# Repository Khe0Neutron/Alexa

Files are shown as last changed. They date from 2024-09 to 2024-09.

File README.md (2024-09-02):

# Proyecto de Control de Luces con Alexa

Este proyecto permite controlar hasta ocho luces en una casa utilizando comandos de voz a través de Amazon Alexa. Está basado en un ESP32, que se conecta a la red WiFi para recibir las órdenes desde Alexa. También se pueden controlar las luces manualmente utilizando botones físicos conectados al ESP32.

## Características

- **Control de luces con Alexa**: Puedes encender y apagar las luces utilizando comandos de voz.
- **Control manual**: Cada luz puede ser controlada manualmente mediante botones físicos conectados al ESP32.
- **Retroalimentación de estado**: El ESP32 proporciona retroalimentación del estado de cada luz tanto a través de la consola serial como del estado del relé.
- **Configuración flexible**: Los nombres de los dispositivos (luces) se pueden personalizar en el código.

## Requisitos

- **Hardware:**
  - ESP32
  - 8 relés para controlar las luces
  - 8 botones físicos para control manual
  - LED para indicar estado de conexión WiFi
  - Conexión WiFi

- **Librerías Arduino:**
  - [`WiFi.h`](https://github.com/espressif/arduino-esp32/tree/master/libraries/WiFi)
  - [`Espalexa.h`](https://github.com/Aircoookie/Espalexa)
  - [`AceButton.h`](https://github.com/bxparks/AceButton)

## Configuración del Hardware

- Los pines del ESP32 están conectados a los relés y a los botones físicos. Aquí están las asignaciones de pines utilizadas en el proyecto:
  - **Relés:**
    - Relé 1: GPIO 23
    - Relé 2: GPIO 22
    - Relé 3: GPIO 21
    - Relé 4: GPIO 19
    - Relé 5: GPIO 18
    - Relé 6: GPIO 5
    - Relé 7: GPIO 25
    - Relé 8: GPIO 26
  - **Botones:**
    - Botón 1: GPIO 13
    - Botón 2: GPIO 12
    - Botón 3: GPIO 14
    - Botón 4: GPIO 27
    - Botón 5: GPIO 33
    - Botón 6: GPIO 32
    - Botón 7: GPIO 15
    - Botón 8: GPIO 4
  - **LED de estado WiFi:** GPIO 2

## Instalación y Configuración

1. **Instalación de librerías:**
   - Asegúrate de tener instaladas las librerías mencionadas en la sección de requisitos.

2. **Configuración de WiFi:**
   - Modifica las siguientes líneas en el código para configurar tu red WiFi:
     ```cpp
     const char* ssid = "Red"; // Cambiar nombre de red
     const char* password = "Contraseña"; // Cambiar contraseña de red
     ```

3. **Compilación y carga:**
   - Compila y sube el código al ESP32 utilizando el IDE de Arduino.

4. **Integración con Alexa:**
   - Una vez que el ESP32 esté conectado a la red WiFi, Alexa detectará los dispositivos automáticamente. Puedes controlar las luces diciendo comandos como "Alexa, enciende la luz de la sala".

## Uso

- **Control con Alexa:** Di "Alexa, enciende/apaga [nombre de la luz]" para controlar las luces.
- **Control manual:** Pulsa el botón físico correspondiente para encender o apagar una luz.

## Contribución

Si encuentras algún error o tienes sugerencias para mejorar el proyecto, siéntete libre de abrir un issue o hacer un pull request.

## Funcionamiento
Instalacion de la placa con un modulo Rele de 8 canales

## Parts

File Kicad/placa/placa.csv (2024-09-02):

Source: | /home/neutron/Documentos/Proyectos/Alexa/Kicad/placa/placa.kicad_sch
Date: | vie 01 dic 2023 10:46:34
Tool: | Eeschema 6.0.2+dfsg-1
Generator: | /usr/share/kicad/plugins/bom_csv_grouped_by_value.py
Component Count: | 8
Individual Components:
Item | Qty | Reference(s) | Value | LibPart | Footprint | Datasheet | Check_prices | Description | MANUFACTURER | MF | MP | PARTREV | Package | STANDARD | SnapEDA_Link
 |  | C1 | C | Device:C | Capacitor_THT:CP_Radial_D4.0mm_P2.00mm | ~
 |  | C2 | C | Device:C | Capacitor_THT:CP_Radial_D4.0mm_P2.00mm | ~
 |  | J1 | Conn_01x02 | Connector_Generic:Conn_01x02 | Connector_PinHeader_2.54mm:PinHeader_1x02_P2.54mm_Vertical | ~
 |  | J2 | Conn_01x02 | Connector_Generic:Conn_01x02 | Connector_PinHeader_2.54mm:PinHeader_1x02_P2.54mm_Vertical | ~
 |  | J3 | Conn_01x10 | Connector_Generic:Conn_01x10 | Connector_PinHeader_2.54mm:PinHeader_1x10_P2.54mm_Vertical | ~
 |  | U1 | ESP32-DEVKITC | ESP32-DEVKITC:ESP32-DEVKITC | ESP32-DEVKITC:MODULE_ESP32-DEVKITC |  | https://www.snapeda.com/parts/ESP32-DEVKITC/Espressif+Systems/view-part/?ref=eda | ESP32-WROOM-32UE series Transceiver; 802.11 b/g/n (Wi-Fi, WiFi, WLAN), Bluetooth ® Smart Ready 4.x Dual Mode Evaluation Board | ESPRESSIF | Espressif Systems | ESP32-DEVKITC | N/A | None | Manufacturer Recommendations | https://www.snapeda.com/parts/ESP32-DEVKITC/Espressif+Systems/view-part/?ref=snap
 |  | U2 | LM1117-3.3 | Regulator_Linear:LM1117-3.3 | lm1117:TO254P1054X470X1955-3 | http://www.ti.com/lit/ds/symlink/lm1117.pdf
 |  | U3 | TXS0108EPW | Logic_LevelTranslator:TXS0108EPW | ESP32-DEVKITC:txs0108 | www.ti.com/lit/ds/symlink/txs0108e.pdf
Collated Components:
Item | Qty | Reference(s) | Value | LibPart | Footprint | Datasheet | Check_prices | Description | MANUFACTURER | MF | MP | PARTREV | Package | STANDARD | SnapEDA_Link
1 | 2 | C1, C2 | C | Device:C | Capacitor_THT:CP_Radial_D4.0mm_P2.00mm | ~
2 | 2 | J1, J2 | Conn_01x02 | Connector_Generic:Conn_01x02 | Connector_PinHeader_2.54mm:PinHeader_1x02_P2.54mm_Vertical | ~
3 | 1 | J3 | Conn_01x10 | Connector_Generic:Conn_01x10 | Connector_PinHeader_2.54mm:PinHeader_1x10_P2.54mm_Vertical | ~
4 | 1 | U1 | ESP32-DEVKITC | ESP32-DEVKITC:ESP32-DEVKITC | ESP32-DEVKITC:MODULE_ESP32-DEVKITC |  | https://www.snapeda.com/parts/ESP32-DEVKITC/Espressif+Systems/view-part/?ref=eda | ESP32-WROOM-32UE series Transceiver; 802.11 b/g/n (Wi-Fi, WiFi, WLAN), Bluetooth ® Smart Ready 4.x Dual Mode Evaluation Board | ESPRESSIF | Espressif Systems | ESP32-DEVKITC | N/A | None | Manufacturer Recommendations | https://www.snapeda.com/parts/ESP32-DEVKITC/Espressif+Systems/view-part/?ref=snap
5 | 1 | U2 | LM1117-3.3 | Regulator_Linear:LM1117-3.3 | lm1117:TO254P1054X470X1955-3 | http://www.ti.com/lit/ds/symlink/lm1117.pdf
6 | 1 | U3 | TXS0108EPW | Logic_LevelTranslator:TXS0108EPW | ESP32-DEVKITC:txs0108 | www.ti.com/lit/ds/symlink/txs0108e.pdf

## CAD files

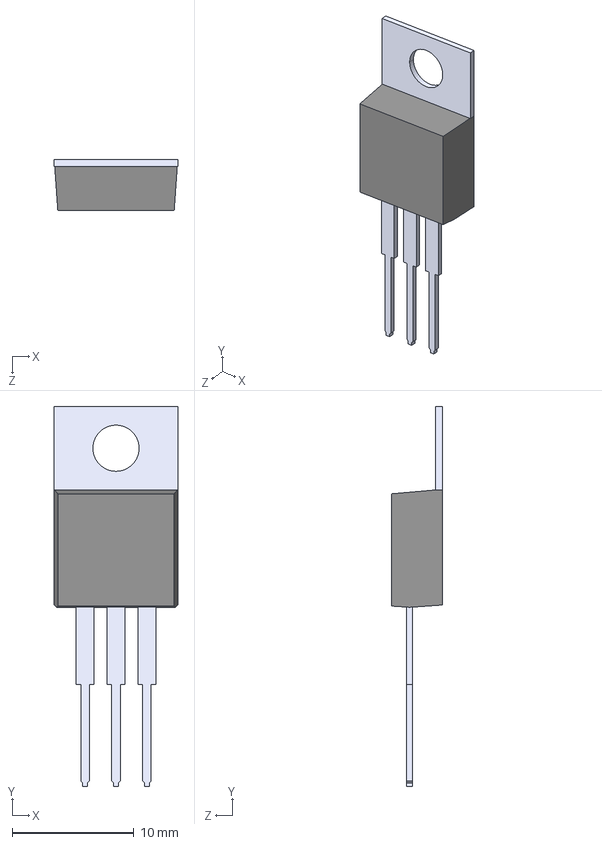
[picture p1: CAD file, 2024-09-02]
Kicad/LM1117T-3.3_NOPB/LM1117T-3.3_NOPB.step
10.2 x 31.2 x 4.20 mm

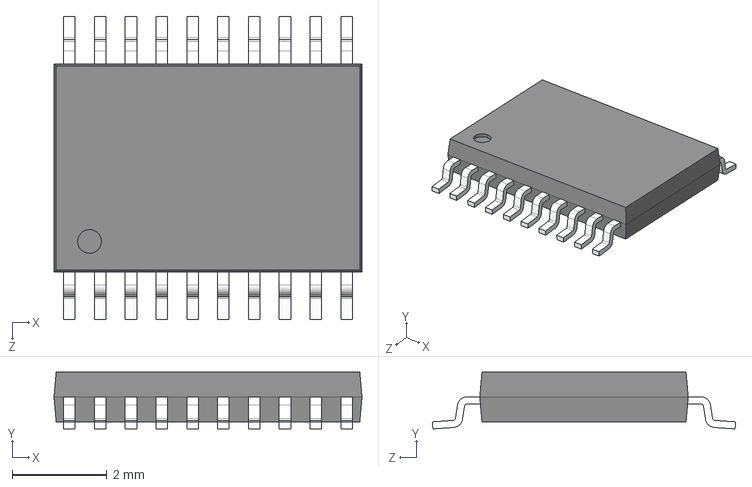
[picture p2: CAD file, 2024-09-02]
Kicad/TXS0108EPW/TXS0108EPW.step
6.50 x 1.20 x 6.40 mm

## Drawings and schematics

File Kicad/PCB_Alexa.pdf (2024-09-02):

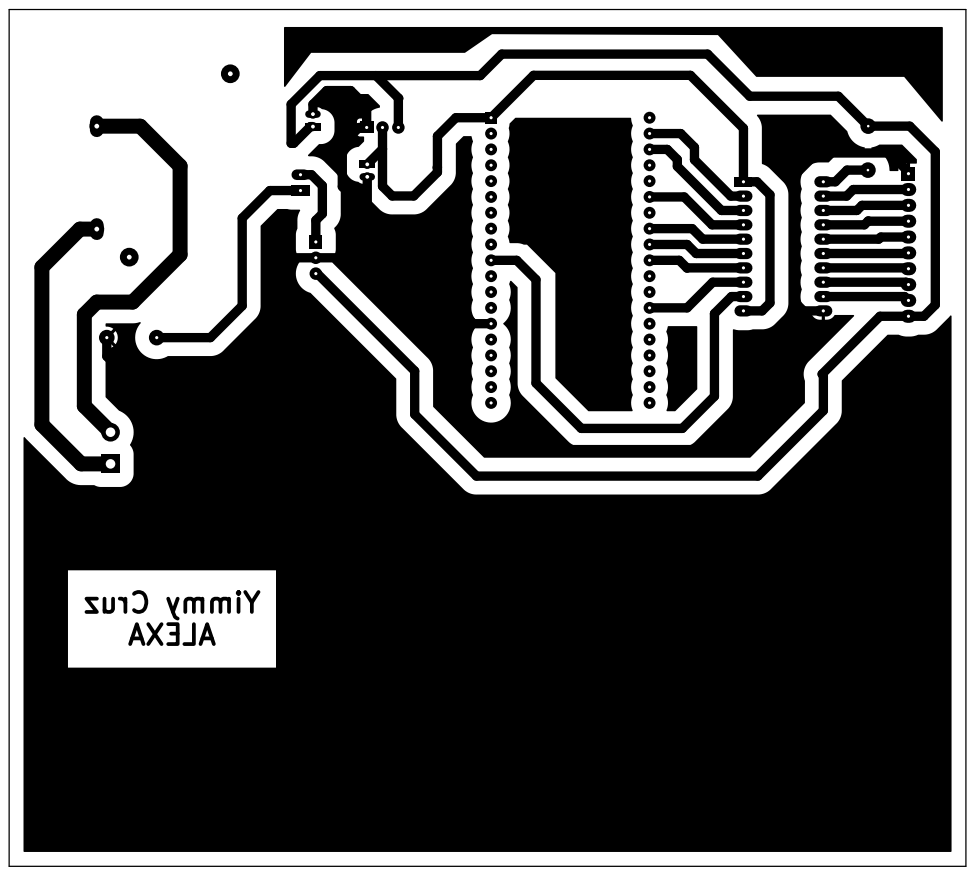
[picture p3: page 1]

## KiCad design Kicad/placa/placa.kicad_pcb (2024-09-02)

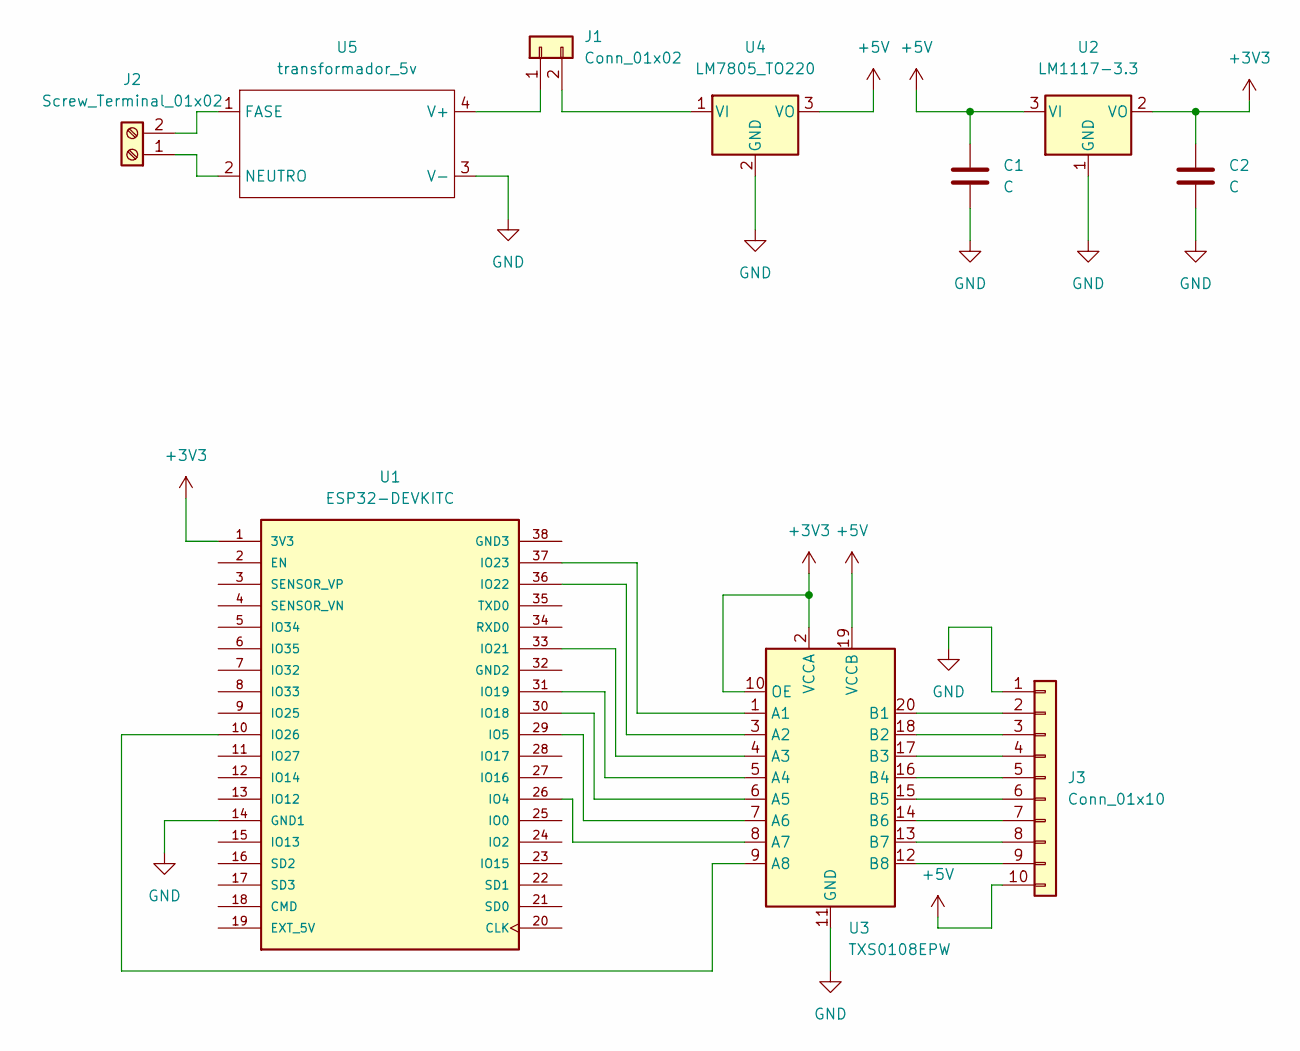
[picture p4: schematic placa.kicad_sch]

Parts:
C1, C2: C; CP_Radial_D4.0mm_P2.00mm
J1: Conn_01x02; PinHeader_1x02_P2.54mm_Vertical
J2: Screw_Terminal_01x02; TerminalBlock_bornier-2_P5.08mm
J3: Conn_01x10; PinHeader_1x10_P2.54mm_Vertical
U1: ESP32-DEVKITC; MODULE_ESP32-DEVKITC; PARTREV N/A
U2: LM1117-3.3; TO254P1054X470X1955-3
U3: TXS0108EPW; txs0108
U4: LM7805_TO220; TO-220-3_Vertical
U5: transformador_5v; TRANSFORMADOR 5V

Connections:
+3V3: C2.1, U1.1 (3V3), U2.2 (VO), U3.2 (VCCA), U3.10 (OE)
+5V: C1.1, J3.10, U2.3 (VI), U3.19 (VCCB), U4.3 (VO)
GND: C1.2, C2.2, J3.1, U1.14 (GND1), U2.1 (GND), U3.11 (GND), U4.2 (GND), U5.3 (V-)
unnamed: J1.1, U5.4 (V+)
unnamed: J1.2, U4.1 (VI)
unnamed: J2.1, U5.2 (NEUTRO)
unnamed: J2.2, U5.1 (FASE)
unnamed: J3.2, U3.20 (B1)
unnamed: J3.3, U3.18 (B2)
unnamed: J3.4, U3.17 (B3)
unnamed: J3.5, U3.16 (B4)
unnamed: J3.6, U3.15 (B5)
unnamed: J3.7, U3.14 (B6)
unnamed: J3.8, U3.13 (B7)
unnamed: J3.9, U3.12 (B8)
unnamed: U1.10 (IO26), U3.9 (A8)
unnamed: U1.26 (IO4), U3.8 (A7)
unnamed: U1.29 (IO5), U3.7 (A6)
unnamed: U1.30 (IO18), U3.6 (A5)
unnamed: U1.31 (IO19), U3.5 (A4)
unnamed: U1.33 (IO21), U3.4 (A3)
unnamed: U1.36 (IO22), U3.3 (A2)
unnamed: U1.37 (IO23), U3.1 (A1)

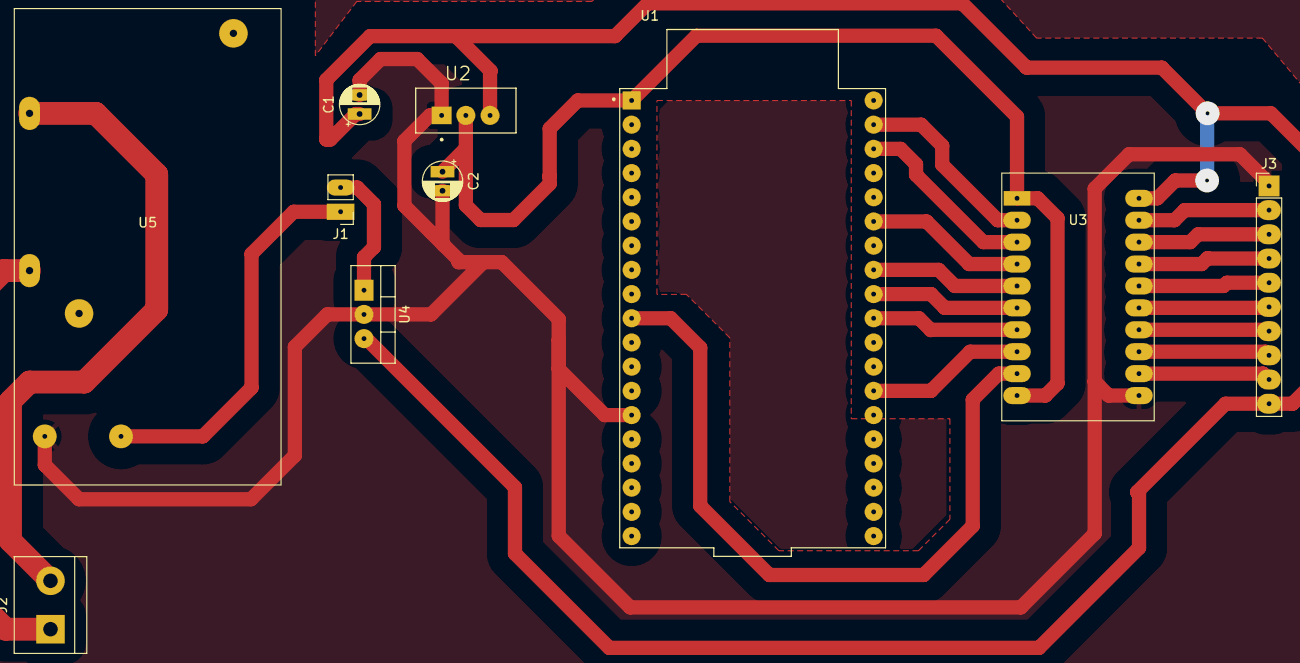
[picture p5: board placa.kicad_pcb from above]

Board: 2 copper layers, 10 parts (0 on the bottom side), 23 nets.

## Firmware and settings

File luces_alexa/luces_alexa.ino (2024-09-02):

#include <WiFi.h>
#include <Espalexa.h>
#include <AceButton.h>
using namespace ace_button;

Espalexa espalexa;

// define the GPIO connected with Relays and switches
#define RelayPin1 23  //D23
#define RelayPin2 22  //D22
#define RelayPin3 21  //D21
#define RelayPin4 19  //D19
#define RelayPin5 18  //D18
#define RelayPin6 5   //D5
#define RelayPin7 25  //D25
#define RelayPin8 26  //D26

#define SwitchPin1 13  //D13
#define SwitchPin2 12  //D12
#define SwitchPin3 14  //D14
#define SwitchPin4 27  //D27
#define SwitchPin5 33  //D33
#define SwitchPin6 32  //D32
#define SwitchPin7 15  //D15
#define SwitchPin8 4   //D4

#define wifiLed    2   //D2

// WiFi Credentials
const char* ssid = "Red"; //cambiar nombre de red
const char* password = "Contraseña"; //CAMBIAR CONTRASEÑA DE RED

// device names
String Device_1_Name = "Luz de la TV";
String Device_2_Name = "Luz de fondo";
String Device_3_Name = "Luz de la sala";
String Device_4_Name = "Luz uno del comedor";
String Device_5_Name = "Luz de la cocina";
String Device_6_Name = "Luz del pasadizo";
String Device_7_Name = "Luz siete";
String Device_8_Name = "Luz dos del comedor";

// prototypes
boolean connectWifi();

//callback functions
void firstLightChanged(uint8_t brightness);
void secondLightChanged(uint8_t brightness);
void thirdLightChanged(uint8_t brightness);
void fourthLightChanged(uint8_t brightness);
void fifthLightChanged(uint8_t brightness);
void sixthLightChanged(uint8_t brightness);
void senventhLightChanged(uint8_t brightness);
void eighthLightChanged(uint8_t brightness);

ButtonConfig config1;
AceButton button1(&config1);
ButtonConfig config2;
AceButton button2(&config2);
ButtonConfig config3;
AceButton button3(&config3);
ButtonConfig config4;
AceButton button4(&config4);
ButtonConfig config5;
AceButton button5(&config5);
ButtonConfig config6;
AceButton button6(&config6);
ButtonConfig config7;
AceButton button7(&config7);
ButtonConfig config8;
AceButton button8(&config8);

void handleEvent1(AceButton*, uint8_t, uint8_t);
void handleEvent2(AceButton*, uint8_t, uint8_t);
void handleEvent3(AceButton*, uint8_t, uint8_t);
void handleEvent4(AceButton*, uint8_t, uint8_t);
void handleEvent5(AceButton*, uint8_t, uint8_t);
void handleEvent6(AceButton*, uint8_t, uint8_t);
void handleEvent7(AceButton*, uint8_t, uint8_t);
void handleEvent8(AceButton*, uint8_t, uint8_t);

boolean wifiConnected = false;

//our callback functions
void firstLightChanged(uint8_t brightness)
{
  //Control the device
  if (brightness == 255)
    {
      digitalWrite(RelayPin1, LOW);
      Serial.println("Device1 ON");
    }
  else
  {
    digitalWrite(RelayPin1, HIGH);
    Serial.println("Device1 OFF");
  }
}

void secondLightChanged(uint8_t brightness)
{
  //Control the device 
  if (brightness == 255)
    {
      digitalWrite(RelayPin2, LOW);
      Serial.println("Device2 ON");
    }
  else
  {
    digitalWrite(RelayPin2, HIGH);
    Serial.println("Device2 OFF");
  }
}

void thirdLightChanged(uint8_t brightness)
{
  //Control the device  
  if (brightness == 255)
    {
      digitalWrite(RelayPin3, LOW);
      Serial.println("Device3 ON");
    }
  else
  {
    digitalWrite(RelayPin3, HIGH);
    Serial.println("Device3 OFF");
  }
}

void fourthLightChanged(uint8_t brightness)
{
  //Control the device 
  if (brightness == 255)
    {
      digitalWrite(RelayPin4, LOW);
      Serial.println("Device4 ON");
    }
  else
  {
    digitalWrite(RelayPin4, HIGH);
    Serial.println("Device4 OFF");
  }
}

void fifthLightChanged(uint8_t brightness)
{
  //Control the device
  if (brightness == 255)
    {
      digitalWrite(RelayPin5, LOW);
      Serial.println("Device5 ON");
    }
  else
  {
    digitalWrite(RelayPin5, HIGH);
    Serial.println("Device1 OFF");
  }
}

void sixthLightChanged(uint8_t brightness)
{
  //Control the device
  if (brightness == 255)
    {
      digitalWrite(RelayPin6, LOW);
      Serial.println("Device6 ON");
    }
  else
  {
    digitalWrite(RelayPin6, HIGH);
    Serial.println("Device6 OFF");
  }
}

void seventhLightChanged(uint8_t brightness)
{
  //Control the device
  if (brightness == 255)
    {
      digitalWrite(RelayPin7, LOW);
      Serial.println("Device7 ON");
    }
  else
  {
    digitalWrite(RelayPin7, HIGH);
    Serial.println("Device7 OFF");
  }
}

void eighthLightChanged(uint8_t brightness)
{
  //Control the device
  if (brightness == 255)
    {
      digitalWrite(RelayPin8, LOW);
      Serial.println("Device8 ON");
    }
  else
  {
    digitalWrite(RelayPin8, HIGH);
    Serial.println("Device8 OFF");
  }
}

// connect to wifi – returns true if successful or false if not
boolean connectWifi()
{
  boolean state = true;
  int i = 0;

  WiFi.mode(WIFI_STA);
  WiFi.begin(ssid, password);
  Serial.println("");
  Serial.println("Connecting to WiFi");

  // Wait for connection
  Serial.print("Connecting...");
  while (WiFi.status() != WL_CONNECTED) {
    delay(500);
    Serial.print(".");
    if (i > 20) {
      state = false; break;
    }
    i++;
  }
  Serial.println("");
  if (state) {
    Serial.print("Connected to ");
    Serial.println(ssid);
    Serial.print("IP address: ");
    Serial.println(WiFi.localIP());
  }
  else {
    Serial.println("Connection failed.");
  }
  return state;
}

void addDevices(){
  // Define your devices here.
  espalexa.addDevice(Device_1_Name, firstLightChanged); //simplest definition, default state off
  espalexa.addDevice(Device_2_Name, secondLightChanged);
  espalexa.addDevice(Device_3_Name, thirdLightChanged);
  espalexa.addDevice(Device_4_Name, fourthLightChanged);
  espalexa.addDevice(Device_5_Name, fifthLightChanged); 
  espalexa.addDevice(Device_6_Name, sixthLightChanged);
  espalexa.addDevice(Device_7_Name, seventhLightChanged);
  espalexa.addDevice(Device_8_Name, eighthLightChanged);

  espalexa.begin();
}

void setup()
{
  Serial.begin(115200);

  pinMode(RelayPin1, OUTPUT);
  pinMode(RelayPin2, OUTPUT);
  pinMode(RelayPin3, OUTPUT);
  pinMode(RelayPin4, OUTPUT);
  pinMode(RelayPin5, OUTPUT);
  pinMode(RelayPin6, OUTPUT);
  pinMode(RelayPin7, OUTPUT);
  pinMode(RelayPin8, OUTPUT);

  pinMode(wifiLed, OUTPUT);

  pinMode(SwitchPin1, INPUT_PULLUP);
  pinMode(SwitchPin2, INPUT_PULLUP);
  pinMode(SwitchPin3, INPUT_PULLUP);
  pinMode(SwitchPin4, INPUT_PULLUP);
  pinMode(SwitchPin5, INPUT_PULLUP);
  pinMode(SwitchPin6, INPUT_PULLUP);
  pinMode(SwitchPin7, INPUT_PULLUP);
  pinMode(SwitchPin8, INPUT_PULLUP);

  //During Starting all Relays should TURN OFF
  digitalWrite(RelayPin1, HIGH);
  digitalWrite(RelayPin2, HIGH);
  digitalWrite(RelayPin3, HIGH);
  digitalWrite(RelayPin4, HIGH);
  digitalWrite(RelayPin5, HIGH);
  digitalWrite(RelayPin6, HIGH);
  digitalWrite(RelayPin7, HIGH);
  digitalWrite(RelayPin8, HIGH);

  config1.setEventHandler(button1Handler);
  config2.setEventHandler(button2Handler);
  config3.setEventHandler(button3Handler);
  config4.setEventHandler(button4Handler);
  config5.setEventHandler(button5Handler);
  config6.setEventHandler(button6Handler);
  config7.setEventHandler(button7Handler);
  config8.setEventHandler(button8Handler);

  button1.init(SwitchPin1);
  button2.init(SwitchPin2);
  button3.init(SwitchPin3);
  button4.init(SwitchPin4);
  button5.init(SwitchPin5);
  button6.init(SwitchPin6);
  button7.init(SwitchPin7);
  button8.init(SwitchPin8);


  // Initialise wifi connection
  wifiConnected = connectWifi();

  if (wifiConnected)
  {
    addDevices();
  }
  else
  {
    Serial.println("Cannot connect to WiFi. So in Manual Mode");
    delay(1000);
  }
}

void loop()
{
   if (WiFi.status() != WL_CONNECTED)
  {
    //Serial.print("WiFi Not Connected ");
    digitalWrite(wifiLed, LOW); //Turn off WiFi LED
  }
  else
  {
    //Serial.print("WiFi Connected  ");
    digitalWrite(wifiLed, HIGH);
    //Manual Switch Control
    //WiFi Control
    if (wifiConnected){
      espalexa.loop();
      delay(1);
    }
    else {
      wifiConnected = connectWifi(); // Initialise wifi connection
      if(wifiConnected){
      addDevices();
      }
    }
  }
  button1.check();
  button2.check();
  button3.check();
  button4.check();
  button5.check();
  button6.check();
  button7.check();
  button8.check();
}

void button1Handler(AceButton* button, uint8_t eventType, uint8_t buttonState) {
  Serial.println("EVENT1");
  EspalexaDevice* d1 = espalexa.getDevice(0); //this will get "first device", the index is zero-based
  switch (eventType) {
    case AceButton::kEventPressed:
      Serial.println("kEventPressed");
      d1->setPercent(100); //set value "brightness" in percent
      digitalWrite(RelayPin1, LOW);
      break;
    case AceButton::kEventReleased:
      Serial.println("kEventReleased");
      d1->setPercent(0); //set value "brightness" in percent
      digitalWrite(RelayPin1, HIGH);
      break;
  }
}

void button2Handler(AceButton* button, uint8_t eventType, uint8_t buttonState) {
  Serial.println("EVENT2");
  EspalexaDevice* d2 = espalexa.getDevice(1);
  switch (eventType) {
    case AceButton::kEventPressed:
      Serial.println("kEventPressed");
      d2->setPercent(100);
      digitalWrite(RelayPin2, LOW);
      break;
    case AceButton::kEventReleased:
      Serial.println("kEventReleased");
      d2->setPercent(0);
      digitalWrite(RelayPin2, HIGH);
      break;
  }
}

void button3Handler(AceButton* button, uint8_t eventType, uint8_t buttonState) {
  Serial.println("EVENT3");
  EspalexaDevice* d3 = espalexa.getDevice(2);
  switch (eventType) {
    case AceButton::kEventPressed:
      Serial.println("kEventPressed");
      d3->setPercent(100);
      digitalWrite(RelayPin3, LOW);
      break;
    case AceButton::kEventReleased:
      Serial.println("kEventReleased");
      d3->setPercent(0);
      digitalWrite(RelayPin3, HIGH);
      break;
  }
}

void button4Handler(AceButton* button, uint8_t eventType, uint8_t buttonState) {
  Serial.println("EVENT4");
  EspalexaDevice* d4 = espalexa.getDevice(3);
  switch (eventType) {
    case AceButton::kEventPressed:
      Serial.println("kEventPressed");
      d4->setPercent(100);
      digitalWrite(RelayPin4, LOW);
      break;
    case AceButton::kEventReleased:
      Serial.println("kEventReleased");
      d4->setPercent(0);
      digitalWrite(RelayPin4, HIGH);
      break;
  }
}

void button5Handler(AceButton* button, uint8_t eventType, uint8_t buttonState) {
  Serial.println("EVENT5");
  EspalexaDevice* d5 = espalexa.getDevice(4);
  switch (eventType) {
    case AceButton::kEventPressed:
      Serial.println("kEventPressed");
      d5->setPercent(100);
      digitalWrite(RelayPin5, LOW);
      break;
    case AceButton::kEventReleased:
      Serial.println("kEventReleased");
      d5->setPercent(0);
      digitalWrite(RelayPin5, HIGH);
      break;
  }
}

void button6Handler(AceButton* button, uint8_t eventType, uint8_t buttonState) {
  Serial.println("EVENT6");
  EspalexaDevice* d6 = espalexa.getDevice(5);
  switch (eventType) {
    case AceButton::kEventPressed:
      Serial.println("kEventPressed");
      d6->setPercent(100);
      digitalWrite(RelayPin6, LOW);
      break;
    case AceButton::kEventReleased:
      Serial.println("kEventReleased");
      d6->setPercent(0);
      digitalWrite(RelayPin6, HIGH);
      break;
  }
}

void button7Handler(AceButton* button, uint8_t eventType, uint8_t buttonState) {
  Serial.println("EVENT7");
  EspalexaDevice* d7 = espalexa.getDevice(6);
  switch (eventType) {
    case AceButton::kEventPressed:
      Serial.println("kEventPressed");
      d7->setPercent(100);
      digitalWrite(RelayPin7, LOW);
      break;
    case AceButton::kEventReleased:
      Serial.println("kEventReleased");
      d7->setPercent(0);
      digitalWrite(RelayPin7, HIGH);
      break;
  }
}

void button8Handler(AceButton* button, uint8_t eventType, uint8_t buttonState) {
  Serial.println("EVENT8");
  EspalexaDevice* d8 = espalexa.getDevice(7);
  switch (eventType) {
    case AceButton::kEventPressed:
      Serial.println("kEventPressed");
      d8->setPercent(100);
      digitalWrite(RelayPin8, LOW);
      break;
    case AceButton::kEventReleased:
      Serial.println("kEventReleased");
      d8->setPercent(0);
      digitalWrite(RelayPin8, HIGH);
      break;
  }
}
